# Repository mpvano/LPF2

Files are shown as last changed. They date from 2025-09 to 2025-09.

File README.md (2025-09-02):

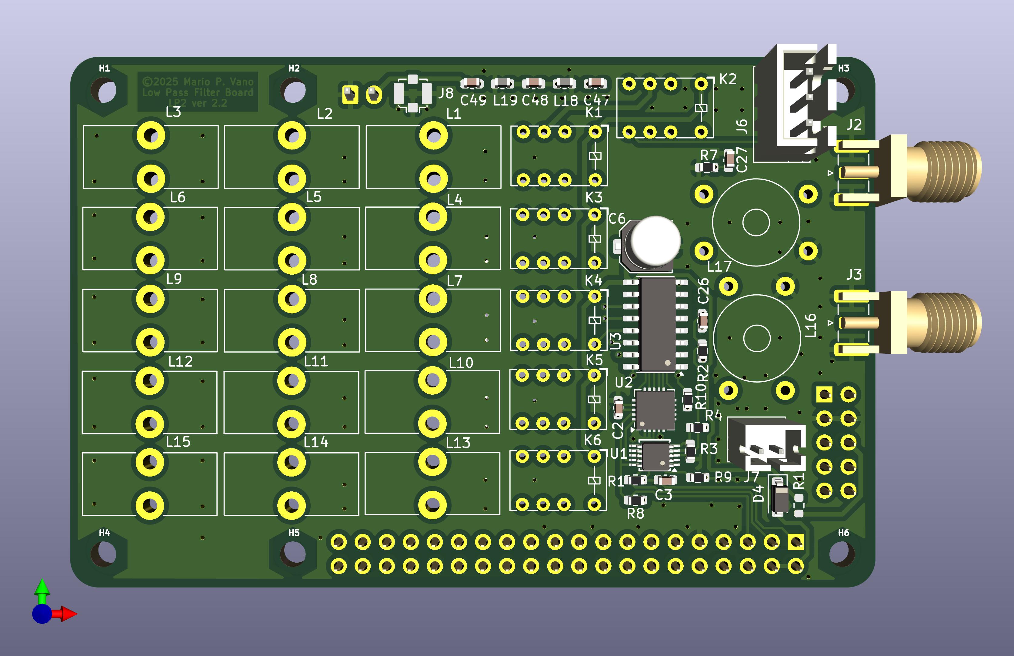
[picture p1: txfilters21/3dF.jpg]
3dView


## The LPF2 Filter Board

LPF2 is a combined Relay Switched Harmonic Filter, Receiver High Pass Filter, VSWR bridge and Antenna Relay board for Low Powered HF Radios. It is designed primarily for use with radio board sets that stack mechanically with the Raspberry Pi. and has been successfully used to build several different radios.

The LPF2 board is compatible for stacking with boards designed to the Raspberry Pi "Hat" specification, although it is not a "hat" as it is the same size as the Pi itself and overhangs the IO connectors. It can also be used as a standalone board with anything that can provide compatible I2C and TX/RX control signals, and 3.3 Volt and Relay Power.

It can be built to use 4.5 Volt relays powered from the GPIO connector or for 12 Volt relays powered from an external source.

## N2ADR Filter Compatibility

The board was designed for limited software compatibility with the popular N2ADR filter board used by the Hermes Lite 2 radio and widely supported in SDR software. The board is NOT completely compatible with N2ADR's design. It differs in the following ways:

  1. The receiver low pass filter is always active - the control bit is IGNORED
  2. There are only 5 Low Pass filters. The control bit for "160 meters" is IGNORED.
  3. The Most significant bit of the control word is wire or'ed with the external Transmit/Receive line allowing software T/R switching.
  4. The VSWR bridge uses a different ADC, so that it does not conflict with any HL2 compatible hardware in the radio - but this means it is not directly displayable by SDR software expecting the HL2 VSWR ADC.

The board has been used primarily with "Radioberry" and "RadioHat" Boards to build 5-10 watt 3-30Mhz Multimode Ham Transceivers.

## Filter Component Selection

The Low Pass Filters are not suitable for extremely dirty power amplifiers. They are designed to reduce the harmonic emissions from properly designed amplifiers within legal limits by reducing the harmonics - not totally eliminating them. As such, they may not work with single ended power amplifiers without modification to the filter values - The design expects the 2nd harmonic to be somewhat reduced by the power amplifier.

The filter component values are based on the popular ones originally published by the RSGB.

The VSWR bridge transformers are conservatively designed so that the diodes are protected in the event of higher power being applied. To improve the sensitivity, reduce the ratio to 10:1 or 7:1 and adjust the software used for power calculation accordingly.

Variations in filter material batches may requre trimming the Toroid coil values by 1 or two turns or spreading or compacting them.

## Hints

I suggest testing the board's logic functionality while assembling it before the relays and filter components are installed since rework is difficult once the relays are in place.

I've also provided the source for a simple TK python program I use to view the VSWR, power and battery voltage in a separate window on my radios.

## Disclaimers

I designed this board for my own use. I have no plans to provide PCBs or boards to others at this time. Hopefully, if there is interest in this board others will provide for group builds, completed boards, or group purchases.

Anyone may use this design for any purpose whatsoever, although I would prefer that it retain some credit to me as the original designer. I will not provide support for any boards using this design that have not been actually built by ME!

If you build any boards or devices using this design, you are totally responsible for any associated liabilities.

This design was only possible thanks to the excellent work done by George Dobbs G3RJV, James Ahlstrom N2ADR, and everyone associated with the HL2 and Radioberry projects.

Mario Vano
AE0GL

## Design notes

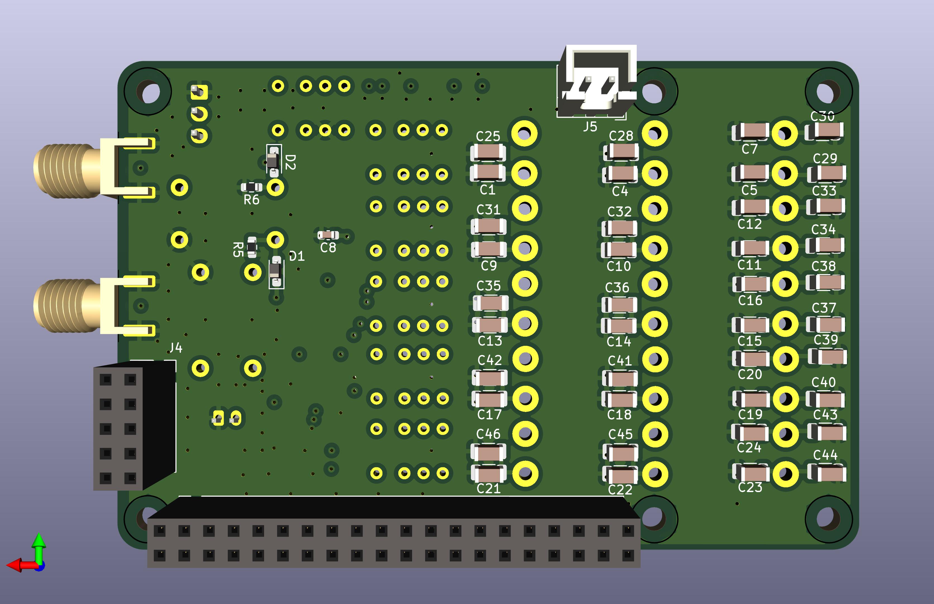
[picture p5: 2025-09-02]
txfilters21/3dB.jpg

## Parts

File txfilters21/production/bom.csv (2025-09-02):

Designator | Footprint | Quantity | Value | LCSC Part #
C1, C7 | 1206 | 2 | 470p
C10, C11 | 1206 | 2 | 680p
C12, C9 | 1206 | 2 | 270p
C13, C16, C22, C23 | 1206 | 4 | 150p
C14, C15, C28, C29 | 1206 | 4 | 390p
C17, C20, C21, C24 | 1206 | 4 | 47p
C18, C19 | 1206 | 2 | 220p
C2, C3, C8 | 0603 | 3 | 100n
C25, C30, C31, C32, C33, C34, C36, C37, C40, C41, C44, C45 | 1206 | 12 | 0p
C26, C27 | 0603 | 2 | 10n
C35, C38, C39, C42 | 1206 | 4 | 33p
C4, C5 | 1206 | 2 | 820p
C43, C46 | 1206 | 2 | 10p
C47, C49 | 0603 | 2 | 2.7n
C48 | 0603 | 1 | 820p
C6 | C_Elec_5x5.8 | 1 | 33µ 25V
D1, D2 | D_SOD-323_HandSoldering | 2 | 1n5711wds
D4 | D_SOD-123 | 1 | MBR0520
H1, H2, H3, H4, H5, H6 | MountingHole_2.7mm_M2.5_KA | 6 | 2.5mm
J1 | PinSocket_2x20_P2.54mm_Vertical | 1 | GPIO
J2 | SMA_Samtec_SMA-J-P-H-ST-EM1_EdgeMount | 1 | Input
J3 | SMA_Samtec_SMA-J-P-H-ST-EM1_EdgeMount | 1 | Antenna
J4 | PinSocket_2x05_P2.54mm_Vertical | 1 | Pwr
J5 | JST_XH_B2B-XH-A_1x02_P2.50mm_Vertical | 1 | RX
J6 | JST_XH_B3B-XH-A_1x03_P2.50mm_Vertical | 1 | PA
J7 | JST_PH_B2B-PH-K_1x02_P2.00mm_Vertical | 1 | PTT IN
J8 | U.FL_Molex_MCRF_73412-0110_Vertical | 1 | RX
K1, K2, K3, K4, K5, K6 | Relay_DPDT_AXICOM_IMSeries_Pitch5.08mm | 6 | IM02TS
L1, L3 | L_Toroid_Vertical_L14.0mm_W6.3mm_P4.57mm_Pulse_A | 2 | 2.42uh
L10, L12 | L_Toroid_Vertical_L14.0mm_W6.3mm_P4.57mm_Pulse_A | 2 | 444n
L11 | L_Toroid_Vertical_L14.0mm_W6.3mm_P4.57mm_Pulse_A | 1 | 561n
L13, L15 | L_Toroid_Vertical_L14.0mm_W6.3mm_P4.57mm_Pulse_A | 2 | 300n
L14 | L_Toroid_Vertical_L14.0mm_W6.3mm_P4.57mm_Pulse_A | 1 | 380n
L16, L17 | Transformer_Toroid_Horizontal_D9.0mm_Amidon-T30 | 2 | T37-43 1:13
L18, L19 | 0603 | 2 | 2.700µ
L2 | L_Toroid_Vertical_L14.0mm_W6.3mm_P4.57mm_Pulse_A | 1 | 3.01uh
L4, L6 | L_Toroid_Vertical_L14.0mm_W6.3mm_P4.57mm_Pulse_A | 2 | 1.38u
L5 | L_Toroid_Vertical_L14.0mm_W6.3mm_P4.57mm_Pulse_A | 1 | 1.70u
L7, L9 | L_Toroid_Vertical_L14.0mm_W6.3mm_P4.57mm_Pulse_A | 2 | 773n
L8 | L_Toroid_Vertical_L14.0mm_W6.3mm_P4.57mm_Pulse_A | 1 | 990n
R1, R2, R7, R8 | 0603 | 4 | 10k
R10 | 0603 | 1 | 3k9
R3, R9 | 0603 | 2 | 1k
R4 | 0603 | 1 | 9.0k
R5, R6 | 0603 | 2 | 51
U1 | TSSOP-10_3x3mm_P0.5mm | 1 | ADS1115IDGS
U2 | QFN-20-1EP_4x4mm_P0.5mm_EP2.5x2.5mm | 1 | MCP23008-xML
U3 | SOIC-16_3.9x9.9mm_P1.27mm | 1 | ULN2003A

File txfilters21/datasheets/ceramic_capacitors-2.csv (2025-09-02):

Datasheet | Image | DK Part # | Mfr Part # | Mfr | Supplier | Description | Stock | Price | @ qty | Min Qty | Package | Series | Product Status | Capacitance | Tolerance | Voltage - Rated | Temperature Coefficient | Operating Temperature | Features | Ratings | Applications | Failure Rate | Mounting Type | Package / Case | Size / Dimension | Height - Seated (Max) | Thickness (Max) | Lead Spacing | Lead Style
https://datasheets.kyocera-avx.com/C0GNP0-KGM.pdf | //mm.digikey.com/Volume0/opasdata/d220001/medias/images/736/1206-%283216-Metric%29-0%2C94mm-J-Code.jpg | 478-KGM31BCG2D221JTTR-ND,478-KGM31BCG2D221JTCT-ND,478-KGM31BCG2D221JTDKR-ND | KGM31BCG2D221JT | KYOCERA AVX | KYOCERA AVX | CAP CER 220PF 200V C0G/NP0 1206 | 26,378 | 0.3 | 0 | 1 | Tape & Reel (TR),Cut Tape (CT),Digi-Reel® | KGM - C0G | Active | 220 pF | ±5% | 200V | C0G, NP0 | -55°C ~ 125°C | - | - | General Purpose | - | Surface Mount, MLCC | 1206 (3216 Metric) | 0.126" L x 0.063" W (3.20mm x 1.60mm) | - | 0.037" (0.94mm) | - | -
https://datasheets.kyocera-avx.com/C0GNP0-KGM.pdf | //mm.digikey.com/Volume0/opasdata/d220001/medias/images/736/1206-%283216-Metric%29-0%2C94mm-J-Code.jpg | 478-KGM31BCG2D151JTTR-ND,478-KGM31BCG2D151JTCT-ND,478-KGM31BCG2D151JTDKR-ND | KGM31BCG2D151JT | KYOCERA AVX | KYOCERA AVX | CAP CER 150PF 200V C0G/NP0 1206 | 18,997 | 0.3 | 0 | 1 | Tape & Reel (TR),Cut Tape (CT),Digi-Reel® | KGM - C0G | Active | 150 pF | ±5% | 200V | C0G, NP0 | -55°C ~ 125°C | - | - | General Purpose | - | Surface Mount, MLCC | 1206 (3216 Metric) | 0.126" L x 0.063" W (3.20mm x 1.60mm) | - | 0.037" (0.94mm) | - | -
https://datasheets.kyocera-avx.com/C0GNP0-KGM.pdf | //mm.digikey.com/Volume0/opasdata/d220001/medias/images/736/1206-%283216-Metric%29-0%2C94mm-J-Code.jpg | 478-KGM31VCG2D471JUTR-ND,478-KGM31VCG2D471JUCT-ND,478-KGM31VCG2D471JUDKR-ND | KGM31VCG2D471JU | KYOCERA AVX | KYOCERA AVX | CAP CER 470PF 200V C0G/NP0 1206 | 27,824 | 0.32 | 0 | 1 | Tape & Reel (TR),Cut Tape (CT),Digi-Reel® | KGM - C0G | Active | 470 pF | ±5% | 200V | C0G, NP0 | -55°C ~ 125°C | - | - | General Purpose | - | Surface Mount, MLCC | 1206 (3216 Metric) | 0.126" L x 0.063" W (3.20mm x 1.60mm) | - | 0.048" (1.22mm) | - | -
https://datasheets.kyocera-avx.com/C0GNP0-KGM.pdf | //mm.digikey.com/Volume0/opasdata/d220001/medias/images/805/1206-%283216-Metric%29-1%2C78mm-Q-Code.jpg | 478-KGM31VCG2D102JUTR-ND,478-KGM31VCG2D102JUCT-ND,478-KGM31VCG2D102JUDKR-ND | KGM31VCG2D102JU | KYOCERA AVX | KYOCERA AVX | CAP CER 1000PF 200V C0G/NP0 1206 | 22,784 | 0.32 | 0 | 1 | Tape & Reel (TR),Cut Tape (CT),Digi-Reel® | KGM - C0G | Active | 1000 pF | ±5% | 200V | C0G, NP0 | -55°C ~ 125°C | - | - | General Purpose | - | Surface Mount, MLCC | 1206 (3216 Metric) | 0.126" L x 0.063" W (3.20mm x 1.60mm) | - | 0.048" (1.22mm) | - | -
https://datasheets.kyocera-avx.com/C0GNP0-KGM.pdf | //mm.digikey.com/Volume0/opasdata/d220001/medias/images/736/1206-%283216-Metric%29-0%2C94mm-J-Code.jpg | 478-KGM31VCG2D681JUTR-ND,478-KGM31VCG2D681JUCT-ND,478-KGM31VCG2D681JUDKR-ND | KGM31VCG2D681JU | KYOCERA AVX | KYOCERA AVX | CAP CER 680PF 200V C0G/NP0 1206 | 13,303 | 0.32 | 0 | 1 | Tape & Reel (TR),Cut Tape (CT),Digi-Reel® | KGM - C0G | Active | 680 pF | ±5% | 200V | C0G, NP0 | -55°C ~ 125°C | - | - | General Purpose | - | Surface Mount, MLCC | 1206 (3216 Metric) | 0.126" L x 0.063" W (3.20mm x 1.60mm) | - | 0.048" (1.22mm) | - | -
https://datasheets.kyocera-avx.com/C0GNP0-KGM.pdf | //mm.digikey.com/Volume0/opasdata/d220001/medias/images/736/1206-%283216-Metric%29-0%2C94mm-J-Code.jpg | 478-KGM31BCG2D101JTTR-ND,478-KGM31BCG2D101JTCT-ND,478-KGM31BCG2D101JTDKR-ND | KGM31BCG2D101JT | KYOCERA AVX | KYOCERA AVX | CAP CER 100PF 200V C0G/NP0 1206 | 241,546 | 0.34 | 0 | 1 | Tape & Reel (TR),Cut Tape (CT),Digi-Reel® | KGM - C0G | Active | 100 pF | ±5% | 200V | C0G, NP0 | -55°C ~ 125°C | - | - | General Purpose | - | Surface Mount, MLCC | 1206 (3216 Metric) | 0.126" L x 0.063" W (3.20mm x 1.60mm) | - | 0.037" (0.94mm) | - | -
https://datasheets.kyocera-avx.com/C0GNP0-KGM.pdf | //mm.digikey.com/Volume0/opasdata/d220001/medias/images/736/1206-%283216-Metric%29-0%2C94mm-J-Code.jpg | 478-KGM31BCG2D330JTTR-ND,478-KGM31BCG2D330JTCT-ND,478-KGM31BCG2D330JTDKR-ND | KGM31BCG2D330JT | KYOCERA AVX | KYOCERA AVX | CAP CER 33PF 200V C0G/NP0 1206 | 12,960 | 0.34 | 0 | 1 | Tape & Reel (TR),Cut Tape (CT),Digi-Reel® | KGM - C0G | Active | 33 pF | ±5% | 200V | C0G, NP0 | -55°C ~ 125°C | - | - | General Purpose | - | Surface Mount, MLCC | 1206 (3216 Metric) | 0.126" L x 0.063" W (3.20mm x 1.60mm) | - | 0.037" (0.94mm) | - | -
https://datasheets.kyocera-avx.com/C0GNP0-KGM.pdf | //mm.digikey.com/Volume0/opasdata/d220001/medias/images/736/1206-%283216-Metric%29-0%2C94mm-J-Code.jpg | 478-KGM31BCG2D470JTTR-ND,478-KGM31BCG2D470JTCT-ND,478-KGM31BCG2D470JTDKR-ND | KGM31BCG2D470JT | KYOCERA AVX | KYOCERA AVX | CAP CER 47PF 200V C0G/NP0 1206 | 8,353 | 0.34 | 0 | 1 | Tape & Reel (TR),Cut Tape (CT),Digi-Reel® | KGM - C0G | Active | 47 pF | ±5% | 200V | C0G, NP0 | -55°C ~ 125°C | - | - | General Purpose | - | Surface Mount, MLCC | 1206 (3216 Metric) | 0.126" L x 0.063" W (3.20mm x 1.60mm) | - | 0.037" (0.94mm) | - | -
https://datasheets.kyocera-avx.com/C0GNP0-KGM.pdf | //mm.digikey.com/Volume0/opasdata/d220001/medias/images/805/1206-%283216-Metric%29-1%2C78mm-Q-Code.jpg | 478-KGM31TCG2D152JUTR-ND,478-KGM31TCG2D152JUCT-ND,478-KGM31TCG2D152JUDKR-ND | KGM31TCG2D152JU | KYOCERA AVX | KYOCERA AVX | CAP CER 1500PF 200V C0G/NP0 1206 | 10,299 | 0.42 | 0 | 1 | Tape & Reel (TR),Cut Tape (CT),Digi-Reel® | KGM - C0G | Active | 1500 pF | ±5% | 200V | C0G, NP0 | -55°C ~ 125°C | - | - | General Purpose | - | Surface Mount, MLCC | 1206 (3216 Metric) | 0.126" L x 0.063" W (3.20mm x 1.60mm) | - | 0.053" (1.35mm) | - | -
https://datasheets.kyocera-avx.com/C0GNP0-KGM.pdf | //mm.digikey.com/Volume0/opasdata/d220001/medias/images/736/1206-%283216-Metric%29-0%2C94mm-J-Code.jpg | 478-KGM31BCG2D121JTTR-ND,478-KGM31BCG2D121JTCT-ND,478-KGM31BCG2D121JTDKR-ND | KGM31BCG2D121JT | KYOCERA AVX | KYOCERA AVX | CAP CER 120PF 200V C0G/NP0 1206 | 14,175 | 0.3 | 0 | 1 | Tape & Reel (TR),Cut Tape (CT),Digi-Reel® | KGM - C0G | Active | 120 pF | ±5% | 200V | C0G, NP0 | -55°C ~ 125°C | - | - | General Purpose | - | Surface Mount, MLCC | 1206 (3216 Metric) | 0.126" L x 0.063" W (3.20mm x 1.60mm) | - | 0.037" (0.94mm) | - | -
https://datasheets.kyocera-avx.com/C0GNP0-KGM.pdf | //mm.digikey.com/Volume0/opasdata/d220001/medias/images/736/1206-%283216-Metric%29-0%2C94mm-J-Code.jpg | 478-KGM31BCG2D271JTTR-ND,478-KGM31BCG2D271JTCT-ND,478-KGM31BCG2D271JTDKR-ND | KGM31BCG2D271JT | KYOCERA AVX | KYOCERA AVX | CAP CER 270PF 200V C0G/NP0 1206 | 11,638 | 0.3 | 0 | 1 | Tape & Reel (TR),Cut Tape (CT),Digi-Reel® | KGM - C0G | Active | 270 pF | ±5% | 200V | C0G, NP0 | -55°C ~ 125°C | - | - | General Purpose | - | Surface Mount, MLCC | 1206 (3216 Metric) | 0.126" L x 0.063" W (3.20mm x 1.60mm) | - | 0.037" (0.94mm) | - | -
https://datasheets.kyocera-avx.com/C0GNP0-KGM.pdf | //mm.digikey.com/Volume0/opasdata/d220001/medias/images/736/1206-%283216-Metric%29-0%2C94mm-J-Code.jpg | 478-KGM31BCG2D331JTTR-ND,478-KGM31BCG2D331JTCT-ND,478-KGM31BCG2D331JTDKR-ND | KGM31BCG2D331JT | KYOCERA AVX | KYOCERA AVX | CAP CER 330PF 200V C0G/NP0 1206 | 7,980 | 0.3 | 0 | 1 | Tape & Reel (TR),Cut Tape (CT),Digi-Reel® | KGM - C0G | Active | 330 pF | ±5% | 200V | C0G, NP0 | -55°C ~ 125°C | - | - | General Purpose | - | Surface Mount, MLCC | 1206 (3216 Metric) | 0.126" L x 0.063" W (3.20mm x 1.60mm) | - | 0.037" (0.94mm) | - | -
https://datasheets.kyocera-avx.com/C0GNP0-KGM.pdf | //mm.digikey.com/Volume0/opasdata/d220001/medias/images/736/1206-%283216-Metric%29-0%2C94mm-J-Code.jpg | 478-KGM31VCG2D561JUTR-ND,478-KGM31VCG2D561JUCT-ND,478-KGM31VCG2D561JUDKR-ND | KGM31VCG2D561JU | KYOCERA AVX | KYOCERA AVX | CAP CER 560PF 200V C0G/NP0 1206 | 19,240 | 0.32 | 0 | 1 | Tape & Reel (TR),Cut Tape (CT),Digi-Reel® | KGM - C0G | Active | 560 pF | ±5% | 200V | C0G, NP0 | -55°C ~ 125°C | - | - | General Purpose | - | Surface Mount, MLCC | 1206 (3216 Metric) | 0.126" L x 0.063" W (3.20mm x 1.60mm) | - | 0.048" (1.22mm) | - | -
https://datasheets.kyocera-avx.com/C0GNP0-KGM.pdf | //mm.digikey.com/Volume0/opasdata/d220001/medias/images/736/1206-%283216-Metric%29-0%2C94mm-J-Code.jpg | 478-KGM31BCG2D180JTTR-ND,478-KGM31BCG2D180JTCT-ND,478-KGM31BCG2D180JTDKR-ND | KGM31BCG2D180JT | KYOCERA AVX | KYOCERA AVX | CAP CER 18PF 200V C0G/NP0 1206 | 15,192 | 0.34 | 0 | 1 | Tape & Reel (TR),Cut Tape (CT),Digi-Reel® | KGM - C0G | Active | 18 pF | ±5% | 200V | C0G, NP0 | -55°C ~ 125°C | - | - | General Purpose | - | Surface Mount, MLCC | 1206 (3216 Metric) | 0.126" L x 0.063" W (3.20mm x 1.60mm) | - | 0.037" (0.94mm) | - | -
https://datasheets.kyocera-avx.com/C0GNP0-KGM.pdf | //mm.digikey.com/Volume0/opasdata/d220001/medias/images/761/1206-%283216-Metric%29-1%2C27mm-M-Code.jpg | 478-KGM31VCG2D821JUTR-ND,478-KGM31VCG2D821JUCT-ND,478-KGM31VCG2D821JUDKR-ND | KGM31VCG2D821JU | KYOCERA AVX | KYOCERA AVX | CAP CER 820PF 200V C0G/NP0 1206 | 8,823 | 0.32 | 0 | 1 | Tape & Reel (TR),Cut Tape (CT),Digi-Reel® | KGM - C0G | Active | 820 pF | ±5% | 200V | C0G, NP0 | -55°C ~ 125°C | - | - | General Purpose | - | Surface Mount, MLCC | 1206 (3216 Metric) | 0.126" L x 0.063" W (3.20mm x 1.60mm) | - | 0.048" (1.22mm) | - | -
https://datasheets.kyocera-avx.com/C0GNP0-KGM.pdf | //mm.digikey.com/Volume0/opasdata/d220001/medias/images/736/1206-%283216-Metric%29-0%2C94mm-J-Code.jpg | 478-KGM31BCG2D391JTTR-ND,478-KGM31BCG2D391JTCT-ND,478-KGM31BCG2D391JTDKR-ND | KGM31BCG2D391JT | KYOCERA AVX | KYOCERA AVX | CAP CER 390PF 200V C0G/NP0 1206 | 8,000 | 0.3 | 0 | 1 | Tape & Reel (TR),Cut Tape (CT),Digi-Reel® | KGM - C0G | Active | 390 pF | ±5% | 200V | C0G, NP0 | -55°C ~ 125°C | - | - | General Purpose | - | Surface Mount, MLCC | 1206 (3216 Metric) | 0.126" L x 0.063" W (3.20mm x 1.60mm) | - | 0.037" (0.94mm) | - | -
https://datasheets.kyocera-avx.com/C0GNP0-KGM.pdf | //mm.digikey.com/Volume0/opasdata/d220001/medias/images/736/1206-%283216-Metric%29-0%2C94mm-J-Code.jpg | 478-KGM31BCG2D150JTTR-ND,478-KGM31BCG2D150JTCT-ND,478-KGM31BCG2D150JTDKR-ND | KGM31BCG2D150JT | KYOCERA AVX | KYOCERA AVX | CAP CER 15PF 200V C0G/NP0 1206 | 6,470 | 0.33 | 0 | 1 | Tape & Reel (TR),Cut Tape (CT),Digi-Reel® | KGM - C0G | Active | 15 pF | ±5% | 200V | C0G, NP0 | -55°C ~ 125°C | - | - | General Purpose | - | Surface Mount, MLCC | 1206 (3216 Metric) | 0.126" L x 0.063" W (3.20mm x 1.60mm) | - | 0.037" (0.94mm) | - | -
https://datasheets.kyocera-avx.com/C0GNP0-KGM.pdf | //mm.digikey.com/Volume0/opasdata/d220001/medias/images/736/1206-%283216-Metric%29-0%2C94mm-J-Code.jpg | 478-KGM31BCG2D100JTTR-ND,478-KGM31BCG2D100JTCT-ND,478-KGM31BCG2D100JTDKR-ND | KGM31BCG2D100JT | KYOCERA AVX | KYOCERA AVX | CAP CER 10PF 200V C0G/NP0 1206 | 3,754 | 0.33 | 0 | 1 | Tape & Reel (TR),Cut Tape (CT),Digi-Reel® | KGM - C0G | Active | 10 pF | ±5% | 200V | C0G, NP0 | -55°C ~ 125°C | - | - | General Purpose | - | Surface Mount, MLCC | 1206 (3216 Metric) | 0.126" L x 0.063" W (3.20mm x 1.60mm) | - | 0.037" (0.94mm) | - | -
https://datasheets.kyocera-avx.com/C0GNP0-KGM.pdf | //mm.digikey.com/Volume0/opasdata/d220001/medias/images/5972/MFG_478%7EKGM-Series.jpg | 478-KGM31VCG2D471JLTR-ND,478-KGM31VCG2D471JLCT-ND,478-KGM31VCG2D471JLDKR-ND | KGM31VCG2D471JL | KYOCERA AVX | KYOCERA AVX | CAP CER 470PF 200V C0G/NP0 1206 | 0 | 0.3 | 0 | 1 | Tape & Reel (TR),Cut Tape (CT),Digi-Reel® | KGM - C0G | Active | 470 pF | ±5% | 200V | C0G, NP0 | -55°C ~ 125°C | - | - | General Purpose | - | Surface Mount, MLCC | 1206 (3216 Metric) | 0.126" L x 0.063" W (3.20mm x 1.60mm) | - | 0.048" (1.22mm) | - | -
https://datasheets.kyocera-avx.com/C0GNP0-KGM.pdf | //mm.digikey.com/Volume0/opasdata/d220001/medias/images/736/1206-%283216-Metric%29-0%2C94mm-J-Code.jpg | 478-KGM31BCG2D220JTTR-ND,478-KGM31BCG2D220JTCT-ND,478-KGM31BCG2D220JTDKR-ND | KGM31BCG2D220JT | KYOCERA AVX | KYOCERA AVX | CAP CER 22PF 200V C0G/NP0 1206 | 0 | 0.34 | 0 | 1 | Tape & Reel (TR),Cut Tape (CT),Digi-Reel® | KGM - C0G | Active | 22 pF | ±5% | 200V | C0G, NP0 | -55°C ~ 125°C | - | - | General Purpose | - | Surface Mount, MLCC | 1206 (3216 Metric) | 0.126" L x 0.063" W (3.20mm x 1.60mm) | - | 0.037" (0.94mm) | - | -

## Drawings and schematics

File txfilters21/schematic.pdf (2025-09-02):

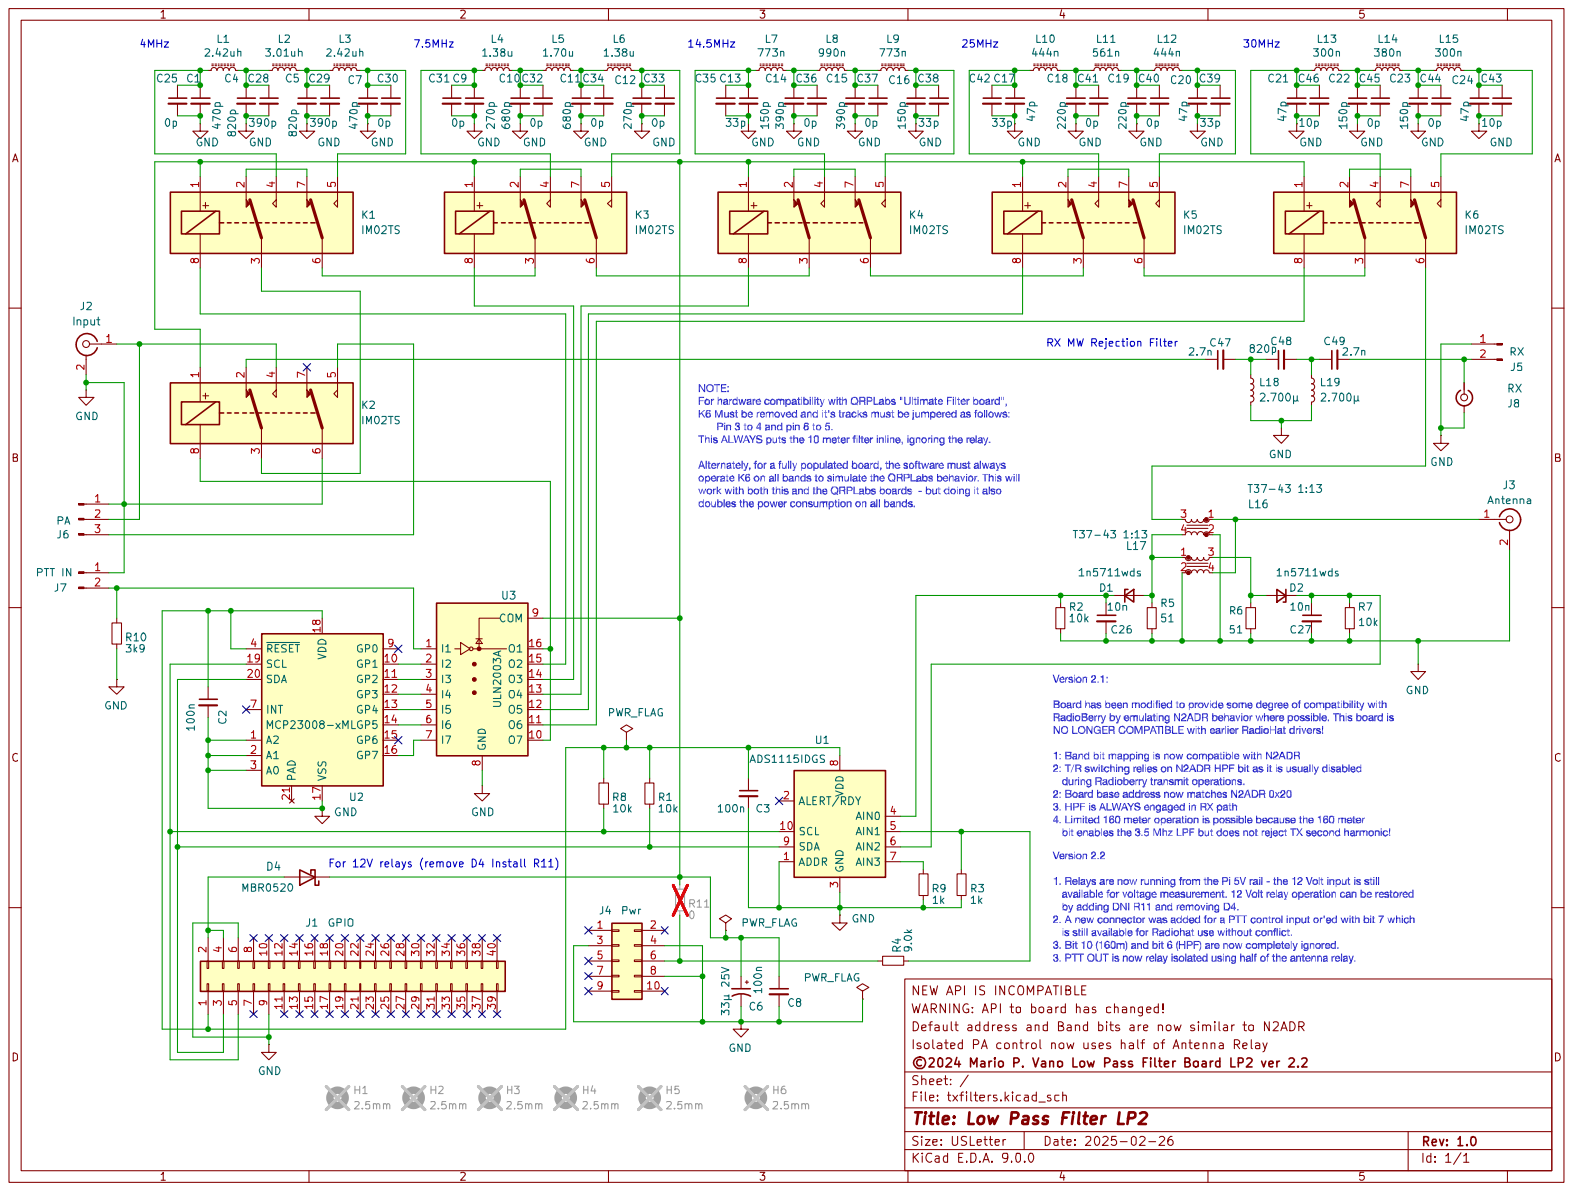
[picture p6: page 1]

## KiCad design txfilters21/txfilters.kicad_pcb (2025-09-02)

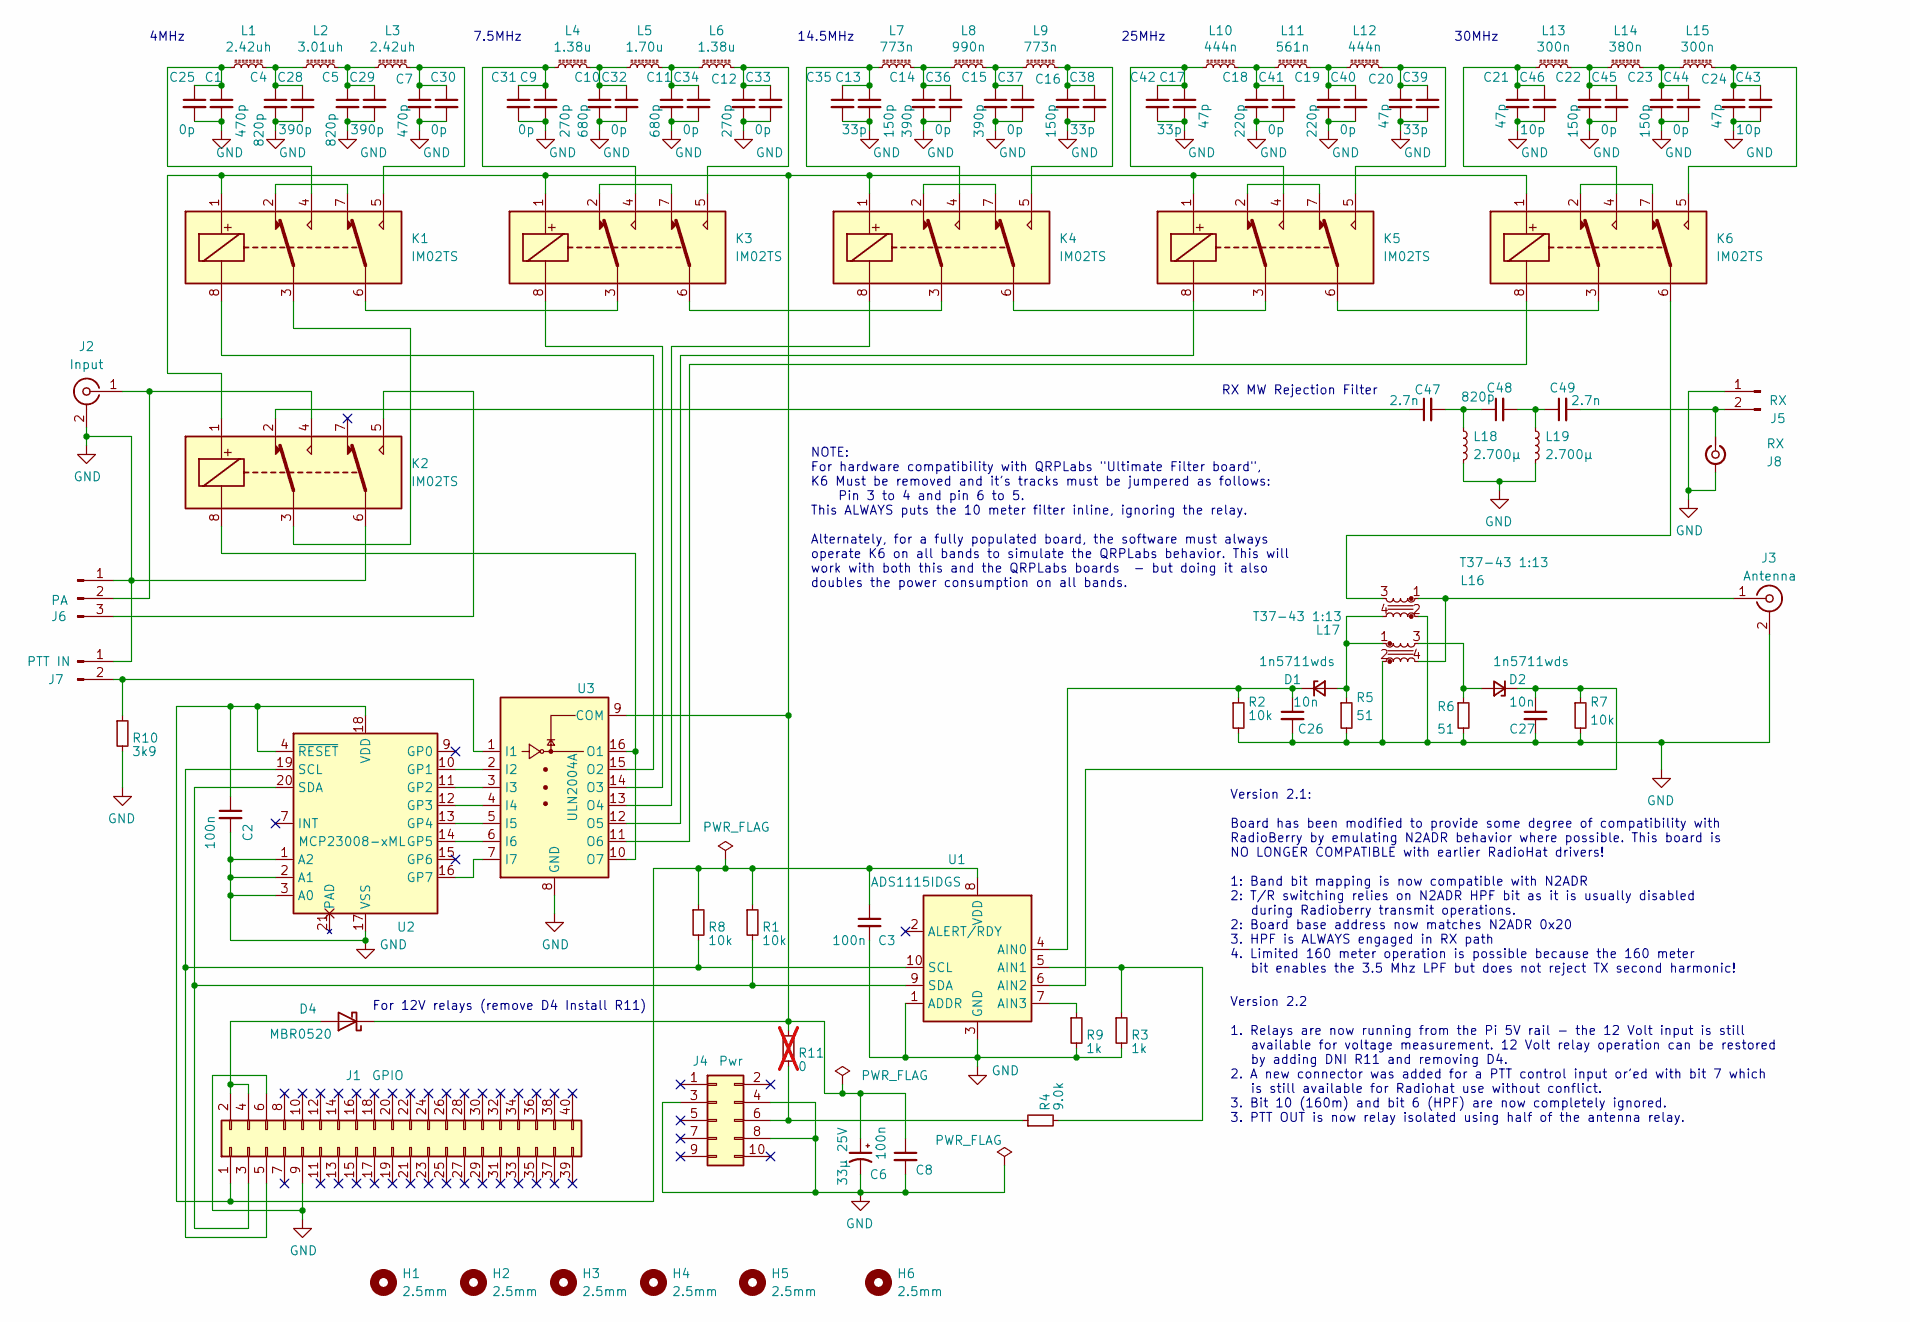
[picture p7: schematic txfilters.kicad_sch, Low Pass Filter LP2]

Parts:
C1, C7: 470p; C_1206_3216Metric; Manufacturer_Part_Number KGM31VCG2D471JU; DigiKey Part Number 478-KGM31VCG2D471JUCT-ND
C2, C3, C8: 100n; C_0603_1608Metric; Manufacturer_Part_Number CL10B104JB8NNNC; DigiKey Part Number 1276-1033-1-ND
C4, C5: 820p; C_1206_3216Metric; Manufacturer_Part_Number KGM31VCG2D821JU; DigiKey Part Number 478-KGM31VCG2D821JUCT-ND
C6: 33µ 25V; C_Elec_5x5.8; Manufacturer_Part_Number EEE-FK1E330UR; DigiKey Part Number PCE3802CT-ND
C9, C12: 270p; C_1206_3216Metric; Manufacturer_Part_Number KGM31BCG2D271JT; DigiKey Part Number 478-KGM31BCG2D271JTCT-ND
C10, C11: 680p; C_1206_3216Metric; Manufacturer_Part_Number KGM31VCG2D681JU; DigiKey Part Number 478-KGM31VCG2D681JUCT-ND
C13, C16, C22, C23: 150p; C_1206_3216Metric; Manufacturer_Part_Number KGM31BCG2D151JT; DigiKey Part Number 478-KGM31BCG2D151JTCT-ND
C14, C15, C28, C29: 390p; C_1206_3216Metric; Manufacturer_Part_Number KGM31BCG2D391JT; DigiKey Part Number 478-KGM31BCG2D391JTCT-ND
C17, C20, C21, C24: 47p; C_1206_3216Metric; Manufacturer_Part_Number KGM31BCG2D470JT; DigiKey Part Number 478-KGM31BCG2D470JTCT-ND
C18, C19: 220p; C_1206_3216Metric; Manufacturer_Part_Number KGM31BCG2D221JT; DigiKey Part Number 478-KGM31BCG2D221JTCT-ND
C25, C30, C31, C32, C33, C34, C36, C37, C40, C41, C44, C45: 0p; C_1206_3216Metric
C26, C27: 10n; C_0603_1608Metric; Manufacturer_Part_Number Samsung Electro-Mechanics; DigiKey Part Number 1276-1091-1-ND
C35, C38, C39, C42: 33p; C_1206_3216Metric; Manufacturer_Part_Number KGM31BCG2D330JT; DigiKey Part Number 478-KGM31BCG2D330JTCT-ND
C43, C46: 10p; C_1206_3216Metric; Manufacturer_Part_Number KGM31BCG2D100JT; DigiKey Part Number 478-KGM31BCG2D100JTCT-ND
C47, C49: 2.7n; C_0603_1608Metric
C48: 820p; C_0603_1608Metric
D1, D2: 1n5711wds; D_SOD-323_HandSoldering; Manufacturer_Part_Number 1N5711WS-7-F; DigiKey Part Number 1N5711WS-FDICT-ND
D4: MBR0520; D_SOD-123; DigiKey Part Number MBR0520LT1G
H1, H2, H3, H4, H5, H6: 2.5mm; MountingHole_2.7mm_M2.5_KA
J1: GPIO; PinSocket_2x20_P2.54mm_Vertical
J2: Input; SMA_Samtec_SMA-J-P-H-ST-EM1_EdgeMount
J3: Antenna; SMA_Samtec_SMA-J-P-H-ST-EM1_EdgeMount
J4: Pwr; PinSocket_2x05_P2.54mm_Vertical
J5: RX; JST_XH_B2B-XH-A_1x02_P2.50mm_Vertical
J6: PA; JST_XH_B3B-XH-A_1x03_P2.50mm_Vertical
J7: PTT IN; JST_PH_B2B-PH-K_1x02_P2.00mm_Vertical
J8: RX; U.FL_Molex_MCRF_73412-0110_Vertical
K1, K2, K3, K4, K5, K6: IM02TS; Relay_DPDT_AXICOM_IMSeries_Pitch5.08mm; Manufacturer_Part_Number 2-1462037; DigiKey Part Number PB1093-ND
L1, L3: 2.42uh; L_Toroid_Vertical_L14.0mm_W6.3mm_P4.57mm_Pulse_A
L2: 3.01uh; L_Toroid_Vertical_L14.0mm_W6.3mm_P4.57mm_Pulse_A
L4, L6: 1.38u; L_Toroid_Vertical_L14.0mm_W6.3mm_P4.57mm_Pulse_A
L5: 1.70u; L_Toroid_Vertical_L14.0mm_W6.3mm_P4.57mm_Pulse_A
L7, L9: 773n; L_Toroid_Vertical_L14.0mm_W6.3mm_P4.57mm_Pulse_A
L8: 990n; L_Toroid_Vertical_L14.0mm_W6.3mm_P4.57mm_Pulse_A
L10, L12: 444n; L_Toroid_Vertical_L14.0mm_W6.3mm_P4.57mm_Pulse_A
L11: 561n; L_Toroid_Vertical_L14.0mm_W6.3mm_P4.57mm_Pulse_A
L13, L15: 300n; L_Toroid_Vertical_L14.0mm_W6.3mm_P4.57mm_Pulse_A
L14: 380n; L_Toroid_Vertical_L14.0mm_W6.3mm_P4.57mm_Pulse_A
L16, L17: T37-43 1:13; Transformer_Toroid_Horizontal_D9.0mm_Amidon-T30
L18, L19: 2.700µ; L_0603_1608Metric
R1, R2, R7, R8: 10k; R_0603_1608Metric; Manufacturer_Part_Number RMCF0603FT10K0; DigiKey Part Number RMCF0603FT10K0CT-ND
R3, R9: 1k; R_0603_1608Metric; Manufacturer_Part_Number RMCF0603FT1K00; DigiKey Part Number RMCF0603FT1K00CT-ND
R4: 9.0k; R_0603_1608Metric; Manufacturer_Part_Number RMCF0603FT9K09; DigiKey Part Number RMCF0603FT9K09CT-ND
R5, R6: 51; R_0603_1608Metric; Manufacturer_Part_Number RMCF0603FT51R0; DigiKey Part Number RMCF0603FT51R0CT-ND
R10: 3k9; R_0603_1608Metric; Manufacturer_Part_Number RMCF0603FT10K0; DigiKey Part Number RMCF0603JT3K90
R11: 0; R_0603_1608Metric; Manufacturer_Part_Number RMCF0603FT10K0; DigiKey Part Number RMCF0603FT10K0CT-ND; not fitted
U1: ADS1115IDGS; TSSOP-10_3x3mm_P0.5mm; Manufacturer_Part_Number ADS1115IDGSR; DigiKey Part Number 296-38849-1-ND
U2: MCP23008-xML; QFN-20-1EP_4x4mm_P0.5mm_EP2.5x2.5mm; Manufacturer_Part_Number MCP23008T-E/ML; DigiKey Part Number MCP23008T-E/MLCT-ND
U3: ULN2004A; SOIC-16_3.9x9.9mm_P1.27mm; Manufacturer_Part_Number ULN2004ADR; DigiKey Part Number 4518-ULN2003ACT-ND

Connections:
GND: C1.2, C2.2, C3.2, C4.2, C5.2, C6.2, C7.2, C8.2, C9.2, C10.2, C11.2, C12.2, C13.2, C14.2, C15.2, C16.2, C17.2, C18.2, C19.2, C20.2, C21.2, C22.2, C23.2, C24.2, C25.2, C26.2, C27.2, C28.2, C29.2, C30.2, C31.2, C32.2, C33.2, C34.2, C35.2, C36.2, C37.2, C38.2, C39.2, C40.2, C41.2, C42.2, C43.2, C44.2, C45.2, C46.2, J1.6, J1.9, J2.2 (Ext), J3.2 (Ext), J4.3, J4.4, J4.8, J5.1, J6.1, J7.1, J8.2 (Ext), K2.6, L16.2, L17.2, L18.2, L19.2, R2.2, R3.2, R5.2, R6.2, R7.2, R9.2, R10.2, U1.1 (ADDR), U1.3 (GND), U2.1 (A2), U2.2 (A1), U2.3 (A0), U2.17 (VSS), U3.8 (GND)
unnamed: C1.1, C25.1, K1.4, L1.2
unnamed: C10.1, C32.1, L4.1, L5.2
unnamed: C11.1, C34.1, L5.1, L6.2
unnamed: C12.1, C33.1, K3.5, L6.1
unnamed: C13.1, C35.1, K4.4, L7.2
unnamed: C14.1, C36.1, L7.1, L8.2
unnamed: C15.1, C37.1, L8.1, L9.2
unnamed: C16.1, C38.1, K4.5, L9.1
unnamed: C17.1, C42.1, K5.4, L10.2
unnamed: C18.1, C41.1, L10.1, L11.2
unnamed: C19.1, C40.1, L11.1, L12.2
unnamed: C20.1, C39.1, K5.5, L12.1
unnamed: C21.1, C46.1, K6.4, L13.2
unnamed: C22.1, C45.1, L13.1, L14.2
unnamed: C23.1, C44.1, L14.1, L15.2
unnamed: C24.1, C43.1, K6.5, L15.1
unnamed: C4.1, C28.1, L1.1, L2.2
unnamed: C5.1, C29.1, L2.1, L3.2
unnamed: C7.1, C30.1, K1.5, L3.1
unnamed: C9.1, C31.1, K3.4, L4.2
unnamed: C47.1, K2.2
unnamed: C47.2, C48.1, L18.1
unnamed: C48.2, C49.1, L19.1
unnamed: D1.2 (A), L16.4, L17.1, R5.1
unnamed: C26.1, D1.1 (K), R2.1, U1.4 (AIN0)
unnamed: D2.2 (A), L17.3, R6.1
unnamed: C27.1, D2.1 (K), R7.1, U1.6 (AIN2)
unnamed: D4.2 (A), J1.2, J1.4
unnamed: C6.1, C8.1, D4.1 (K), K1.1, K2.1, K3.1, K4.1, K5.1, K6.1, R11.1, U3.9 (COM)
unnamed: C2.1, C3.1, J1.1, R1.1, R8.1, U1.8 (VDD), U2.4 (~RESET), U2.18 (VDD)
unnamed: J1.3, R1.2, U1.9 (SDA), U2.20 (SDA)
unnamed: J1.5, R8.2, U1.10 (SCL), U2.19 (SCL)
unnamed: J2.1 (In), J6.2, K2.4
unnamed: J3.1 (In), L16.1, L17.4
unnamed: J4.6, R4.1, R11.2
unnamed: C49.2, J5.2, J8.1 (In)
unnamed: J6.3, K2.5
unnamed: J7.2, R10.1, U3.1 (I1)
unnamed: K1.2, K1.7
unnamed: K1.3, K2.3
unnamed: K1.6, K3.3
unnamed: K3.2, K3.7
unnamed: K3.6, K4.3
unnamed: K4.2, K4.7
unnamed: K4.6, K5.3
unnamed: K5.2, K5.7
unnamed: K5.6, K6.3
unnamed: K6.2, K6.7
unnamed: K6.6, L16.3
unnamed: R3.1, R4.2, U1.5 (AIN1)
unnamed: R9.1, U1.7 (AIN3)
unnamed: U2.10 (GP1), U3.2 (I2)
unnamed: U2.11 (GP2), U3.3 (I3)
unnamed: U2.12 (GP3), U3.4 (I4)
unnamed: U2.13 (GP4), U3.5 (I5)
unnamed: U2.14 (GP5), U3.6 (I6)
unnamed: U2.16 (GP7), U3.7 (I7)
unnamed: K2.8, U3.10 (O7), U3.16 (O1)
unnamed: K1.8, U3.15 (O2)
unnamed: K3.8, U3.14 (O3)
unnamed: K4.8, U3.13 (O4)
unnamed: K5.8, U3.12 (O5)
unnamed: K6.8, U3.11 (O6)

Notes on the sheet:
30MHz
7.5MHz
Version 2.1: Board has been modified to provide some degree of compatibility with RadioBerry by emulating N2ADR behavior where possible. This board is NO LONGER COMPATIBLE with earlier RadioHat drivers! 1: Band bit mapping is now compatible with N2ADR 2: T/R switching relies on N2ADR HPF bit as it 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
25MHz
RX MW Rejection Filter
4MHz
14.5MHz
Version 2.2 1. Relays are now running from the Pi 5V rail - the 12 Volt input is still available for voltage measurement. 12 Volt relay operation can be restored by adding DNI R11 and removing D4. 2. A new connector was added for a PTT control input or'ed with bit 7 which is still available for Rad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
NOTE: For hardware compatibility with QRPLabs "Ultimate Filter board", K6 Must be removed and it's tracks must be jumpered as follows: Pin 3 to 4 and pin 6 to 5. This ALWAYS puts the 10 meter filter inline, ignoring the relay. Alternately, for a fully populated board, the software must always opera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
For 12V relays (remove D4 Install R11)

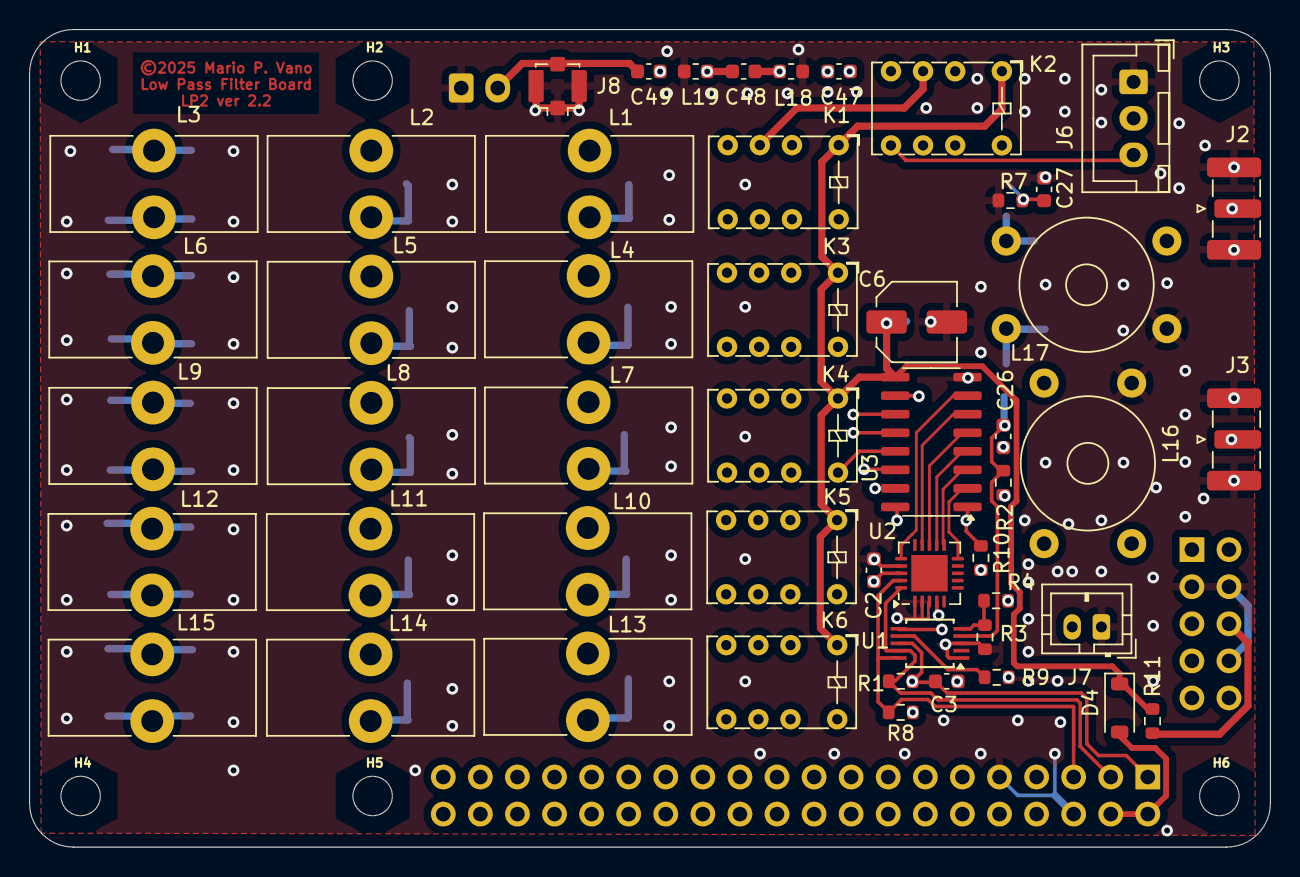
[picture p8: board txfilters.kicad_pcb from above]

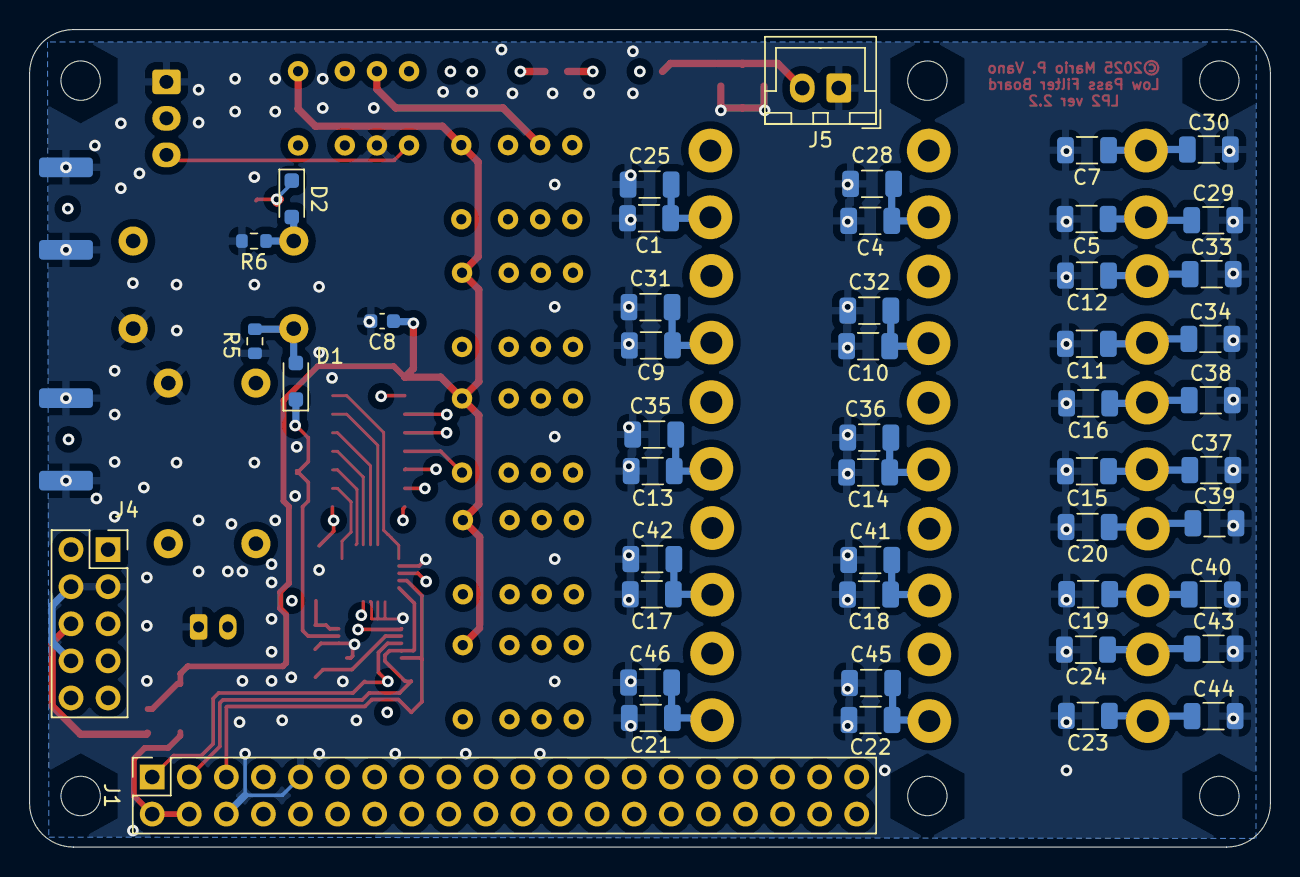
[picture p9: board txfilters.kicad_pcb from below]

Board: 4 copper layers, 85.0 x 56.0 mm, 105 parts (48 on the bottom side), 64 nets.

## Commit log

2025-09-02 Initial Upload
    [bom.csv, ceramic_capacitors-2.csv, designators.csv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]
2025-09-02 kicad ignores
2025-09-02 Added sample VSWR display
    Added a simple TK python program for viewing the VSWR, power and battery voltage in a "kilroy" window peeking over the top of your SDR program..

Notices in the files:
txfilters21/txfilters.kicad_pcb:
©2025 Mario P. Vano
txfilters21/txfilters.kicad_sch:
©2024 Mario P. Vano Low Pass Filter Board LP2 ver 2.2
